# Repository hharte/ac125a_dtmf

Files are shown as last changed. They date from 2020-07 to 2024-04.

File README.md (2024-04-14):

# OKI AC125A Crossbar PBX DTMF Adapter

The OKI AC125A Crossbar PBX has provision for dual DTMF converters connected to 50-pin telco connector #6.  This project consists of a carrier board containing two [WE 755A PBX DTMF Converter](https://github.com/hharte/we755a_dtmf) boards.  This adapter plugs directly into connector #6.

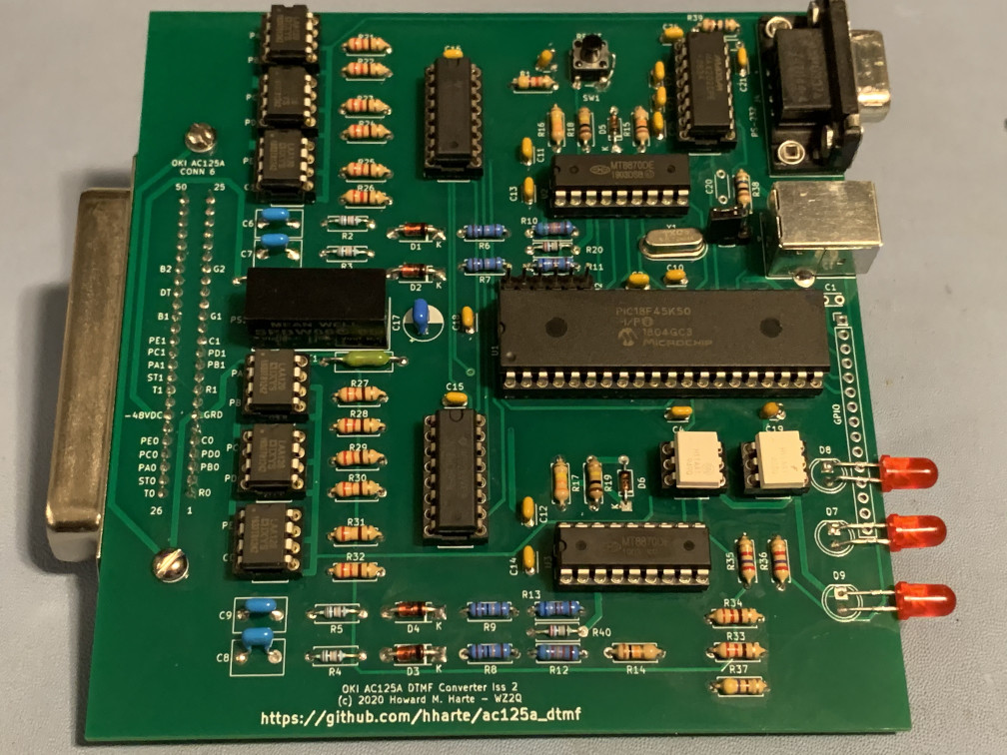
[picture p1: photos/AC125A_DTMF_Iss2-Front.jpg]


# Current Status

The Issue 3 board is being fabbed.  Operational status is not yet known.

The Issue 2 board has been brought up and is in operation on the PBX, available via [C*NET](https://www.ckts.info/) at 1-558-2500 and on [NPSTN](http://www.npstn.us/) at 558-2500.

## Bill of Materials

[Interactive BOM](https://html-preview.github.io/?url=https://github.com/hharte/ac125a_dtmf/blob/main/hardware/bom/ibom.html)

# Installation

Just plug the AC125A DTMF converter into 50-pin connector J6 of the PBX.

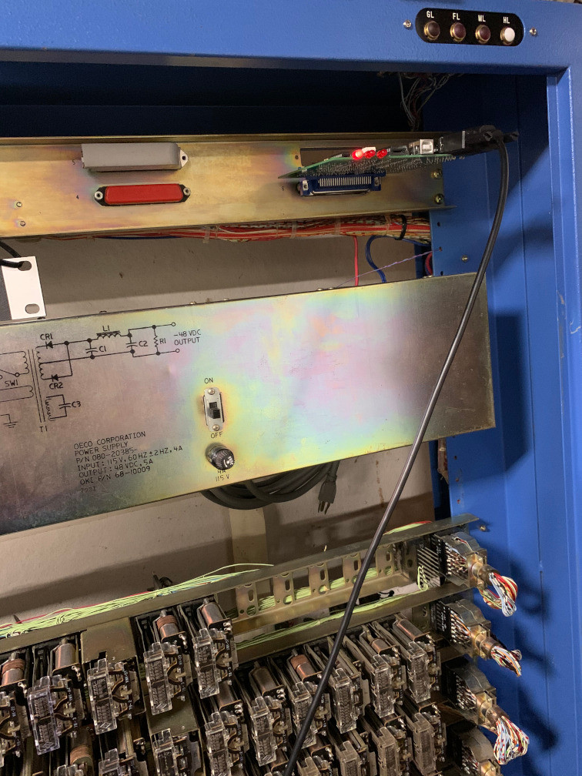
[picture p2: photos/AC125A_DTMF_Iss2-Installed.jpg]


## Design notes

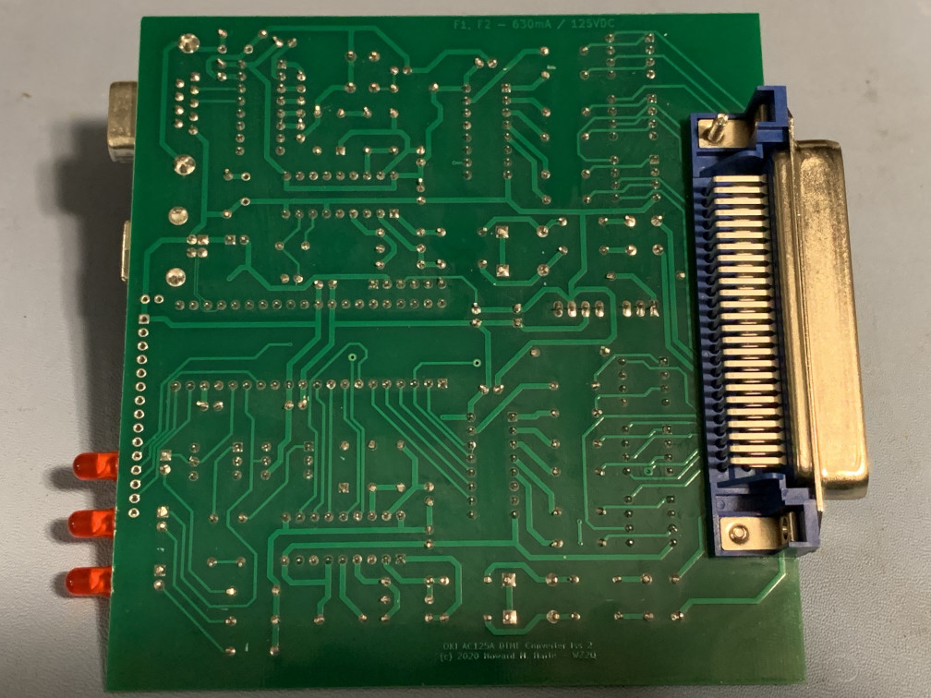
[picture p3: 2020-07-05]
photos/AC125A_DTMF_Iss2-Back.jpg

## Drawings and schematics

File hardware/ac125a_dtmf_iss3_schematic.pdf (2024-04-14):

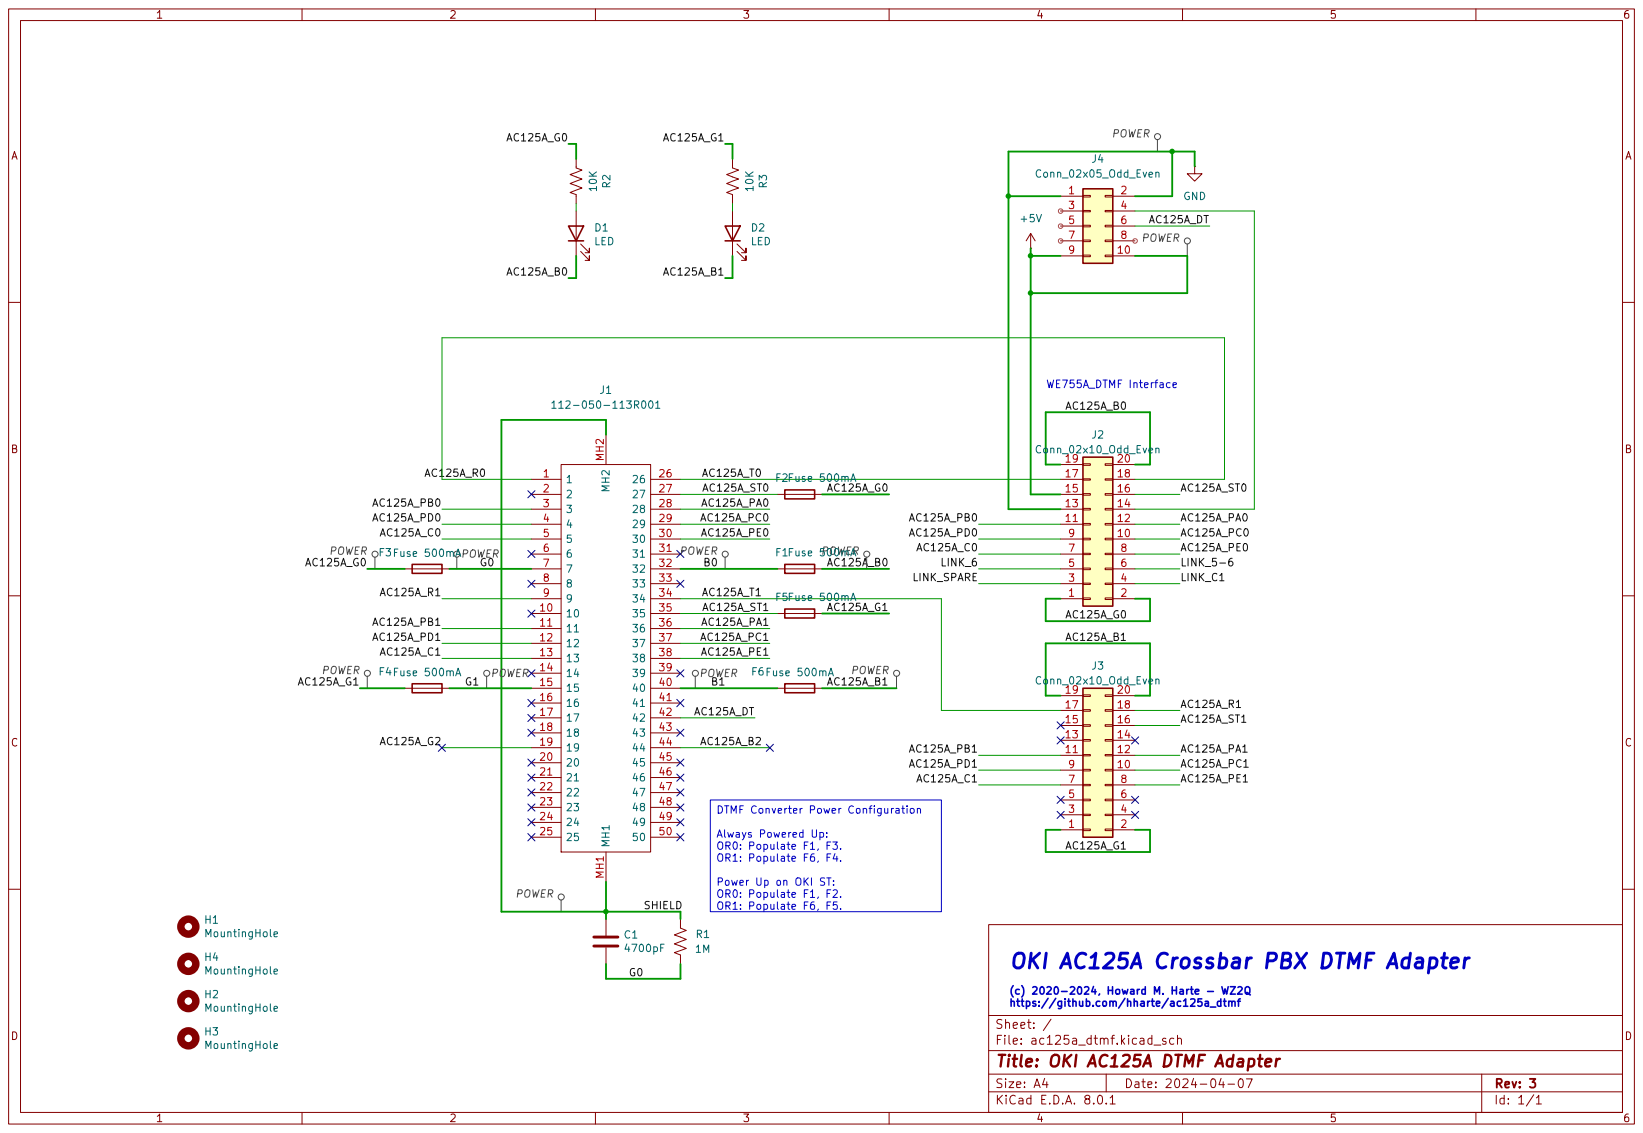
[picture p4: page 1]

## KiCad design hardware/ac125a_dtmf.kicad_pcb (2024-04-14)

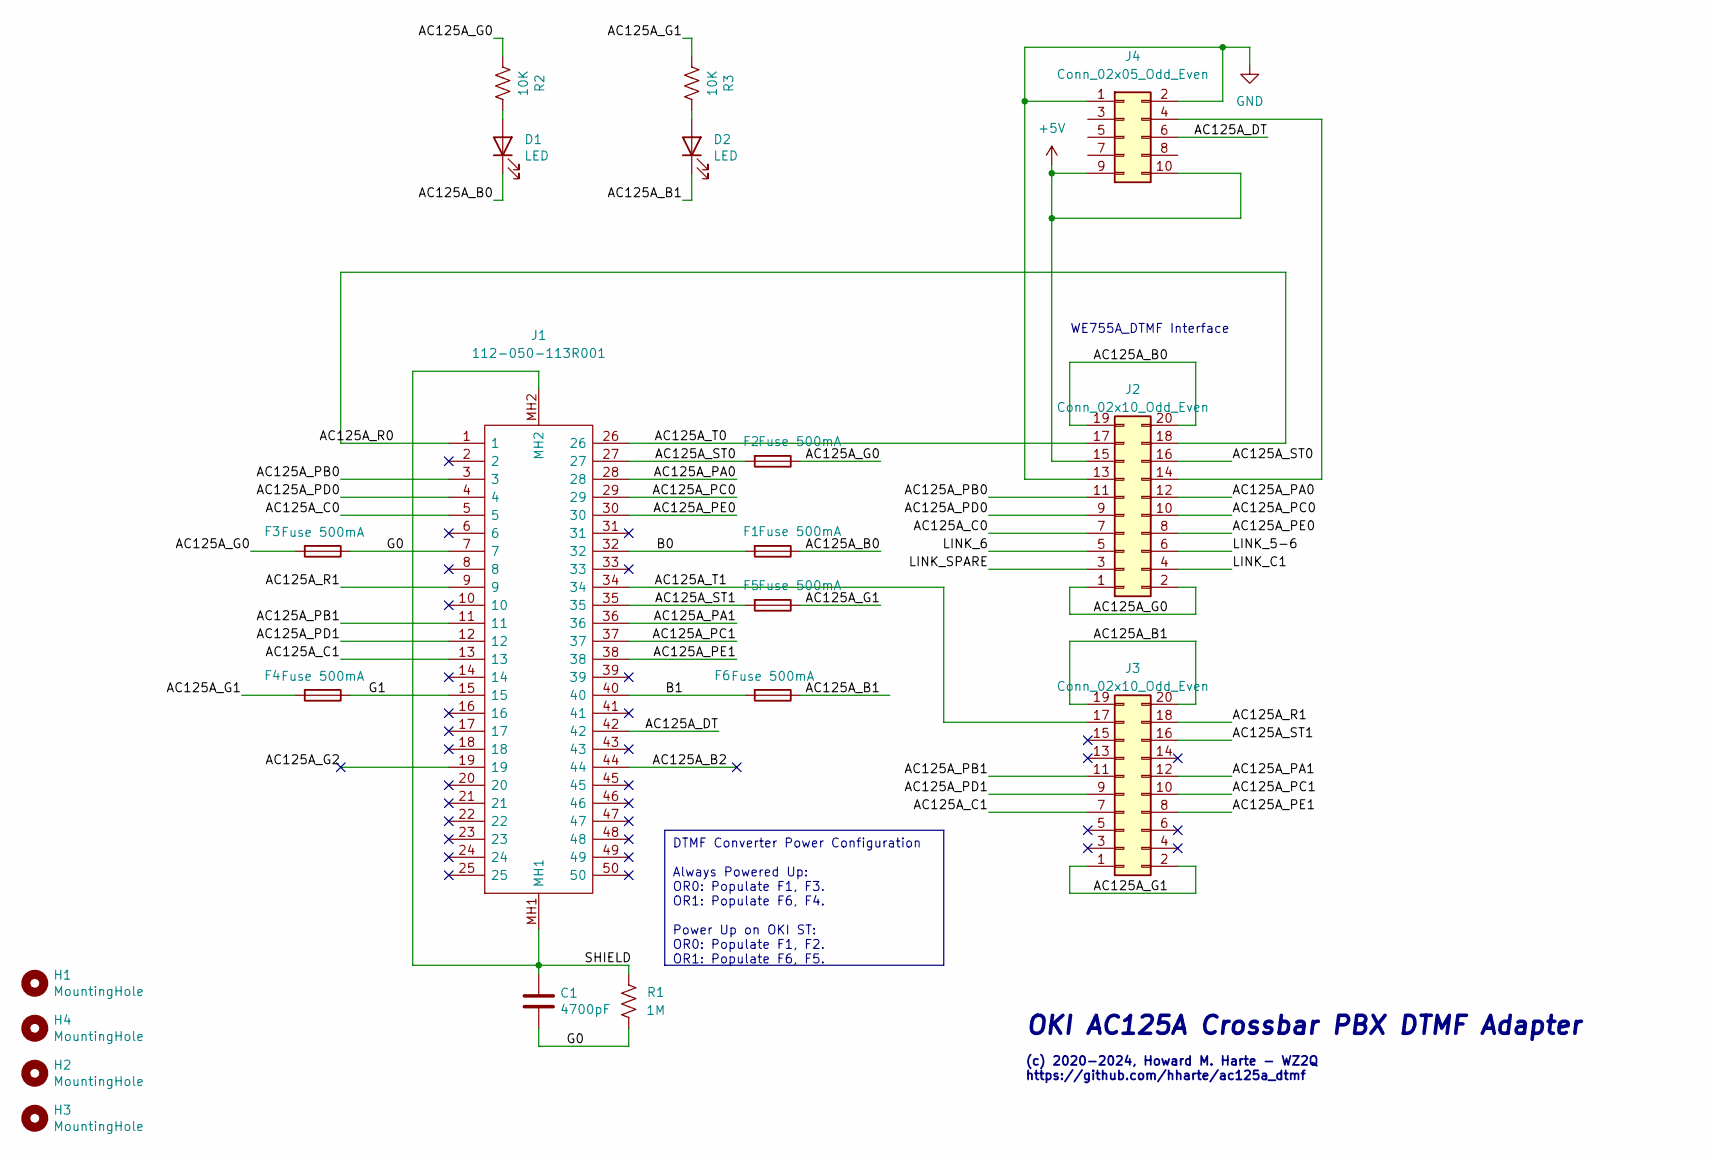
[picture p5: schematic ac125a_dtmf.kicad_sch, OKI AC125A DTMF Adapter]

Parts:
C1: 4700pF; C_Disc_D4.3mm_W1.9mm_P5.00mm; MPN S472M39Z5UN63J5R; Digi-Key_PN 1288PH-ND
D1, D2: LED; LED_D5.0mm; MPN XLUR12D; Digi-Key_PN 1497-1031-ND
F1, F2, F3, F4, F5, F6: Fuse 500mA; R_Axial_DIN0207_L6.3mm_D2.5mm_P10.16mm_Horizontal; MPN 0251.500MXL; Digi-Key_PN F2311-ND
H1, H2, H3, H4: MountingHole; MountingHole_2.7mm_Pad
J1: 112-050-113R001; 112050113R001; Mouser Part Number 636-112-050-113R001
J2, J3: Conn_02x10_Odd_Even; WE755A-DTMF; MPN SFH11-PBPC-D10-ST-BK; Digi-Key_PN S9197-ND
J4: Conn_02x05_Odd_Even; PinHeader_2x05_P2.54mm_Vertical; MPN SFH11-PBPC-D05-ST-BK; Digi-Key_PN S9194-ND
R1: 1M; R_Axial_DIN0207_L6.3mm_D2.5mm_P7.62mm_Horizontal; MPN CFM12JT1M00; Digi-Key_PN S1MHCT-ND
R2, R3: 10K; R_Axial_DIN0207_L6.3mm_D2.5mm_P7.62mm_Horizontal; MPN CFM12JT10K0; Digi-Key_PN S10KHCT-ND

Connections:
+5V: J2.15, J4.9, J4.10
/AC125A_B0: D1.1 (K), F1.1, J2.19, J2.20
/AC125A_B1: D2.1 (K), F6.1, J3.19, J3.20
/AC125A_B2: J1.44
/AC125A_C0: J1.5, J2.7
/AC125A_C1: J1.13, J3.7
/AC125A_DT: J1.42, J4.6
/AC125A_G0: F2.1, F3.2, J2.1, J2.2, R2.2
/AC125A_G1: F4.2, F5.1, J3.1, J3.2, R3.2
/AC125A_G2: J1.19
/AC125A_PA0: J1.28, J2.12
/AC125A_PA1: J1.36, J3.12
/AC125A_PB0: J1.3, J2.11
/AC125A_PB1: J1.11, J3.11
/AC125A_PC0: J1.29, J2.10
/AC125A_PC1: J1.37, J3.10
/AC125A_PD0: J1.4, J2.9
/AC125A_PD1: J1.12, J3.9
/AC125A_PE0: J1.30, J2.8
/AC125A_PE1: J1.38, J3.8
/AC125A_R0: J1.1, J2.18
/AC125A_R1: J1.9, J3.18
/AC125A_ST0: F2.2, J1.27, J2.16
/AC125A_ST1: F5.2, J1.35, J3.16
/AC125A_T0: J1.26, J2.17
/AC125A_T1: J1.34, J3.17
/B0: F1.2, J1.32
/B1: F6.2, J1.40
/G0: C1.2, F3.1, J1.7, R1.2
/G1: F4.1, J1.15
/LINK_5-6: J2.6
/LINK_6: J2.5
/LINK_C1: J2.4
/LINK_SPARE: J2.3
/SHIELD: C1.1, J1.MH1, J1.MH2, R1.1
GND: J2.13, J4.1, J4.2
unnamed: D1.2 (A), R2.1
unnamed: D2.2 (A), R3.1
unnamed: J2.14, J4.4

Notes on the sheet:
DTMF Converter Power Configuration Always Powered Up: OR0: Populate F1, F3. OR1: Populate F6, F4. Power Up on OKI ST: OR0: Populate F1, F2. OR1: Populate F6, F5.
OKI AC125A Crossbar PBX DTMF Adapter
WE755A_DTMF Interface
(c) 2020-2024, Howard M. Harte - WZ2Q https://github.com/hharte/ac125a_dtmf

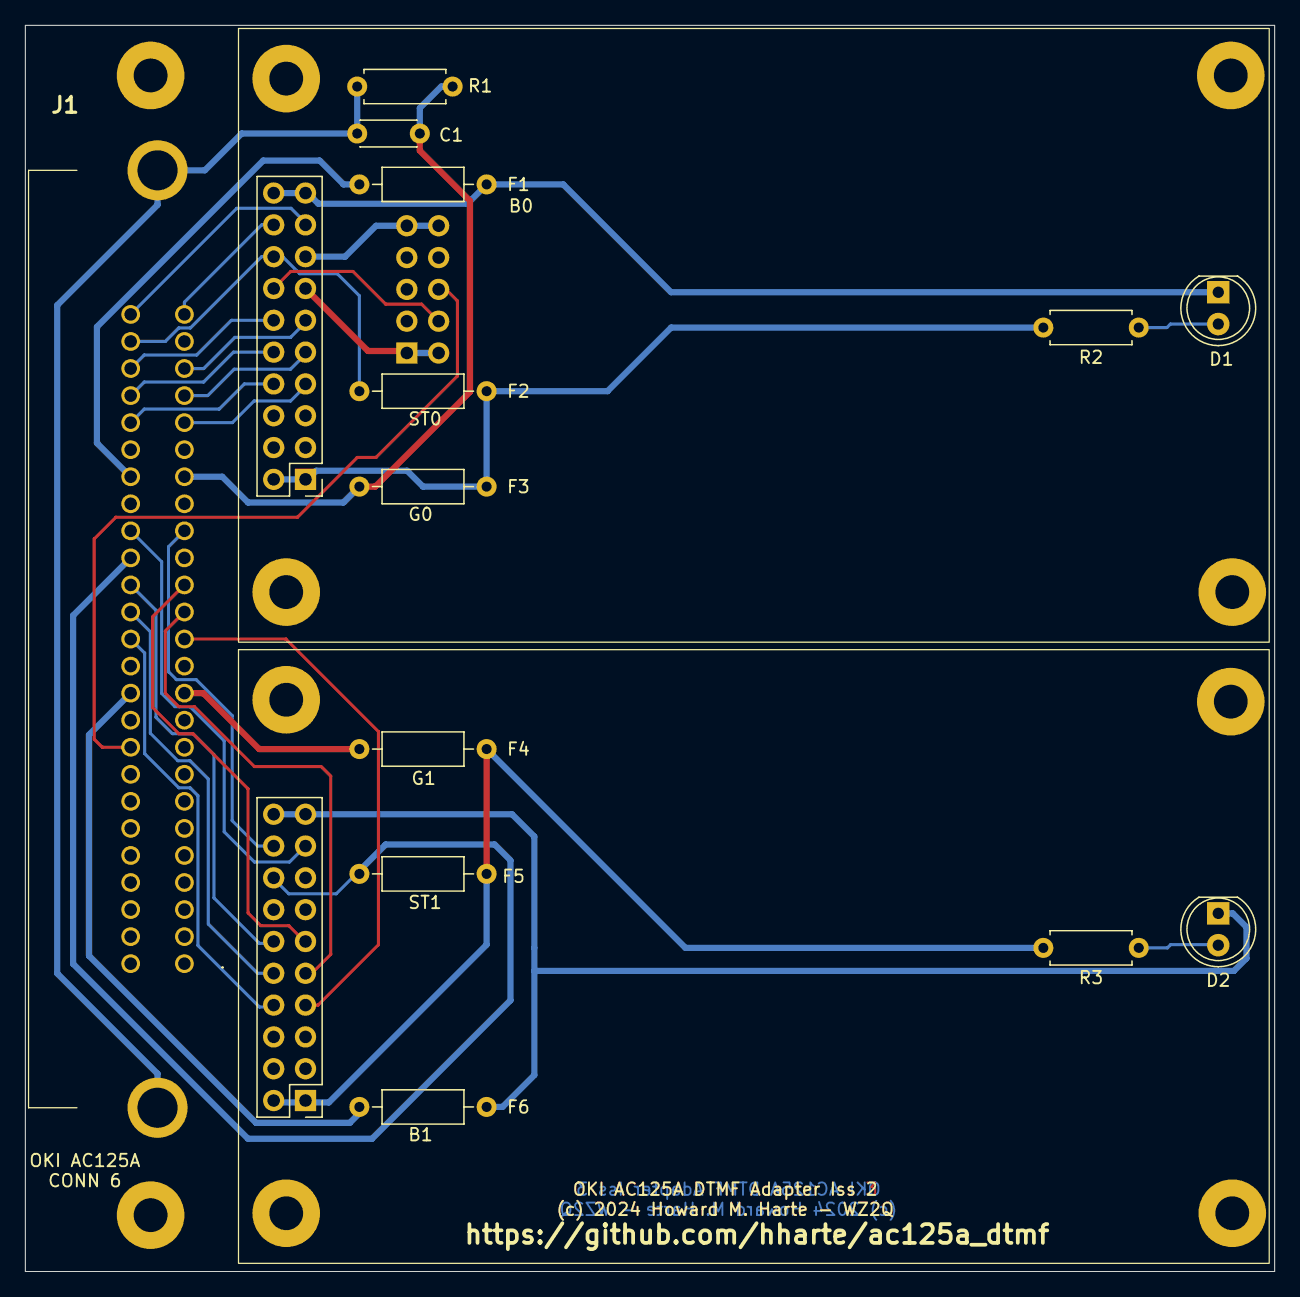
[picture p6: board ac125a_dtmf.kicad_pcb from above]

Board: 2 copper layers, 99.8 x 99.5 mm, 20 parts (1 on the bottom side), 33 nets.

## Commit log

2020-05-24 Initial Issue 1 board bringup.
    This is not complete, but it is useful for testing
    the hardware.
2020-05-30 AC125A DTMF Converter Issue 1
    Schematic (pdf) and gerber files sent to pcbway.com
    [DTMF_Decoder.sch, Microcontroller.sch, SSR_Drivers.sch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]
2020-05-31 Update schematic for Issue 2.
    [DTMF_Decoder.sch, Microcontroller.sch, SSR_Drivers.sch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]
2020-06-20 Add event buffer to track OR operations.
2020-06-20 Update resistor values for DTMF decoders.
    [DTMF_Decoder.sch]
2020-06-27 Final schematic and PCB layout for Issue 2.
    Corrected errors in Issue 1 and fabbed out the PCB.
    [DTMF_Decoder.sch, Microcontroller.sch, SSR_Drivers.sch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]
2020-07-05 Add photos of the Issue 2 PCB.
2022-07-25 Update schematic/layout to KiCAD 6.0
    [DTMF_Decoder.kicad_sch, DTMF_Decoder.sch, Microcontroller.kicad_sch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]
2022-08-07 Fix a couple DRC errors in the layout.
    [DTMF_Decoder.kicad_sch, Microcontroller.kicad_sch, SSR_Drivers.kicad_sch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]
2024-04-14 Issue 3: Utilize we755a_dtmf boards.
    * Carrier for 2*we755a_dtmf boards.
    [DTMF_Decoder.kicad_sch, Microcontroller.kicad_sch, SSR_Drivers.kicad_sch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]

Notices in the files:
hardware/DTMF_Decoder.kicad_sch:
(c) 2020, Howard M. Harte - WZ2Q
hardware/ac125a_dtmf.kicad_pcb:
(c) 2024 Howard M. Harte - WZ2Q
